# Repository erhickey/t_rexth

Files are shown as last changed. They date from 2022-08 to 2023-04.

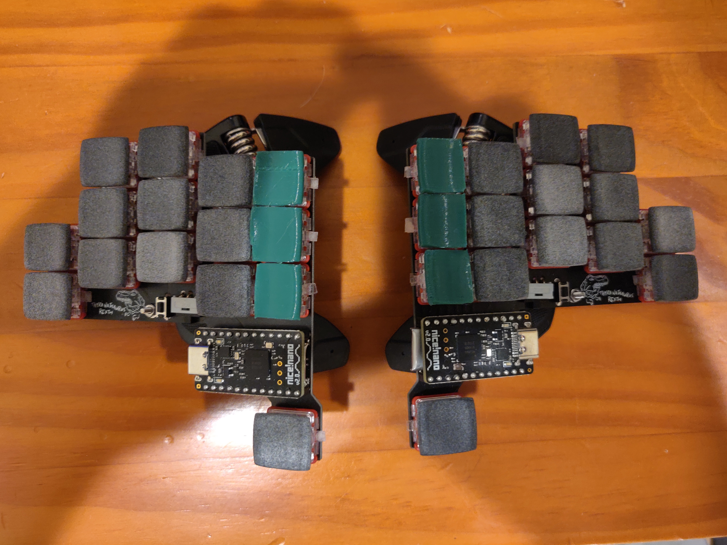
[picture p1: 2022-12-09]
pics/choc30_double.jpg

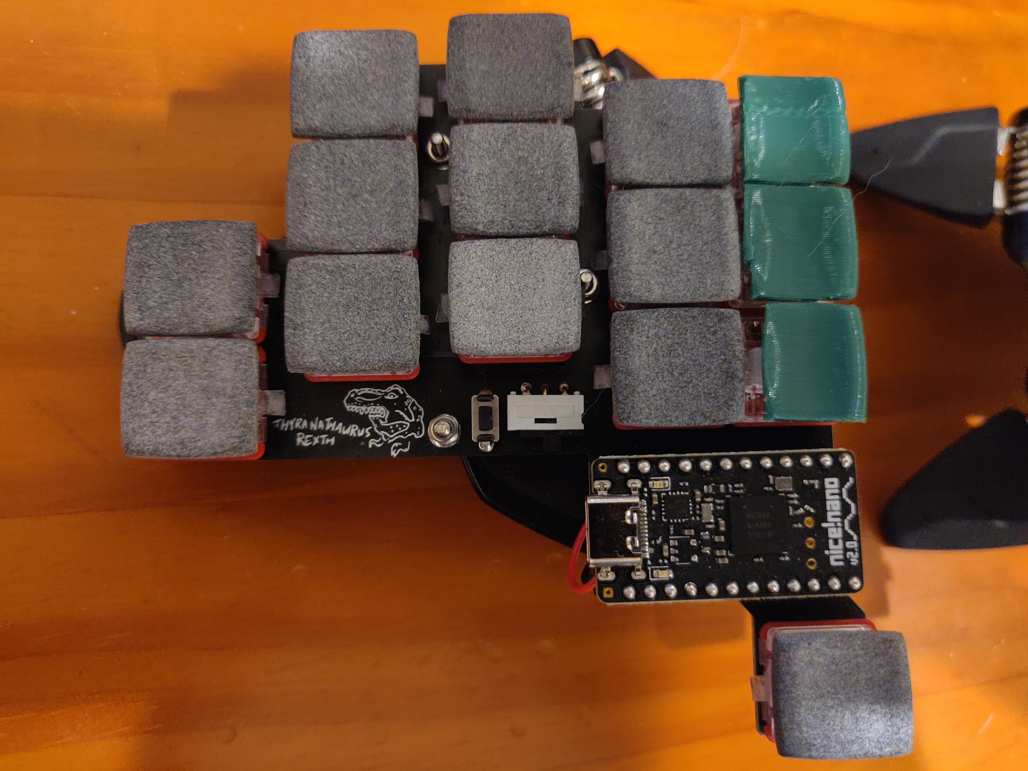
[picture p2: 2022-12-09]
pics/choc30_single.jpg

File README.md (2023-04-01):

# Thyranathaurus Rexth

t-rexth

## About

- Split Keyboard
- Wireless
- Ortholinear
- 36 keys
- MX switch compatible
- Hot swap sockets
- Tenting puck compatible

### Notes

PCB track width and spacing is 0.15mm. Make sure your manufacturer is capable of printing boards with those specs. I used [JLCPCB](https://jlcpcb.com/capabilities/pcb-capabilities).

## Credits/Thanks

- Motivated by [Ben Vallack's videos](https://www.youtube.com/channel/UC4NNPgQ9sOkBjw6GlkgCylg)
- Created with [Ergogen v3](https://github.com/ergogen/ergogen)
- Lots of help from members of [Ergogen Discord](https://discord.gg/nbKcAZB)
- Keycaps by [Pseudoku](https://github.com/pseudoku/PseudoMakeMeKeyCapProfiles)
- Artwork by [Perce](https://madebyperce.com)
- Tenting Puck by [lacohe](https://www.thingiverse.com/thing:5336898)

## Parts

| Type | Part | Manufacturer |
|---|---|---|
| Tactile Button | [C&K PTS636 SP43 LFS](https://www.mouser.com/ProductDetail/CK/PTS636-SP43-LFS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) | [C&K Switches](https://www.ckswitches.com/media/2779/pts636.pdf) |
| Slide Switch | [EAO 09.10290.01](https://www.mouser.com/ProductDetail/EAO/091029001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) | [EAO](https://eao.com) |
| Machine Pin Sockets | [Mill-Max 801 INTERCONNECT MACHINED PIN SOCKET](https://www.mouser.com/ProductDetail/Mill-Max/801-47-012-10-012000?qs=5aG0NVq1C4x40xNvDlnKzg%3D%3D) | [Mill-Max](https://www.mill-max.com/products/socket/801-xx-xxx-10-012000) |
| Socket Pins | [Mill-Max 3330 Straight Pin](https://www.mouser.com/ProductDetail/Mill-Max/3330-0-00-15-00-00-03-0?qs=s8Nb1z4Wn%2FSwJBcI97lmUw%3D%3D) | [Mill-Max](https://www.mill-max.com/products/pin/3330) |
| JST PH 2.0 Connector | [TE 1775469-2](https://www.mouser.com/ProductDetail/TE-Connectivity/1775469-2?qs=fvVej%2FMj3jdYOde%252BssG5lg%3D%3D) | [TE Connectivity](https://www.te.com/usa-en/product-1775469-2.html) |

## Choc 30

The [choc30](./choc30) folder contains the first design of this keyboard. It has 30 keys, requires choc compatible switches, and has minimal y spacing. I abandoned that version for a couple reasons. I found the keycaps and spacing too small, and I could not find an enjoyable 30 key layout.

If you are interested in that version beware of a couple issues:

- Attempting to solder battery wires onto the PCB without shorting your battery can be tricky.
- The spacing between the innermost columns is not wide enough, thus the philadelphia minimalist keycaps [do not fit both columns](./pics/choc30_single.jpg).

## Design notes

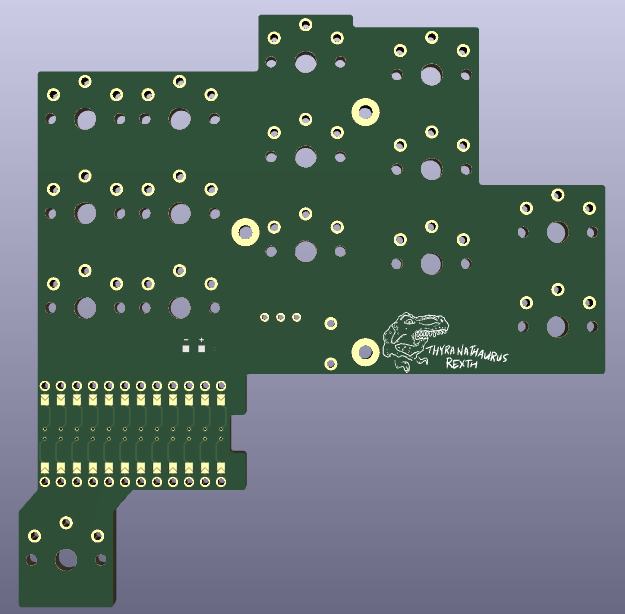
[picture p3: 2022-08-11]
pics/choc30_pcb_3d.png

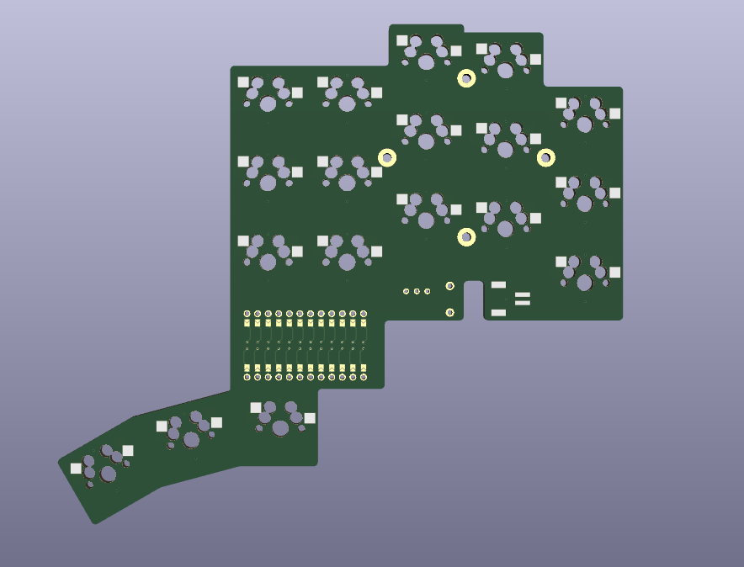
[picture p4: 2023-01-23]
pics/pcb_3d.png

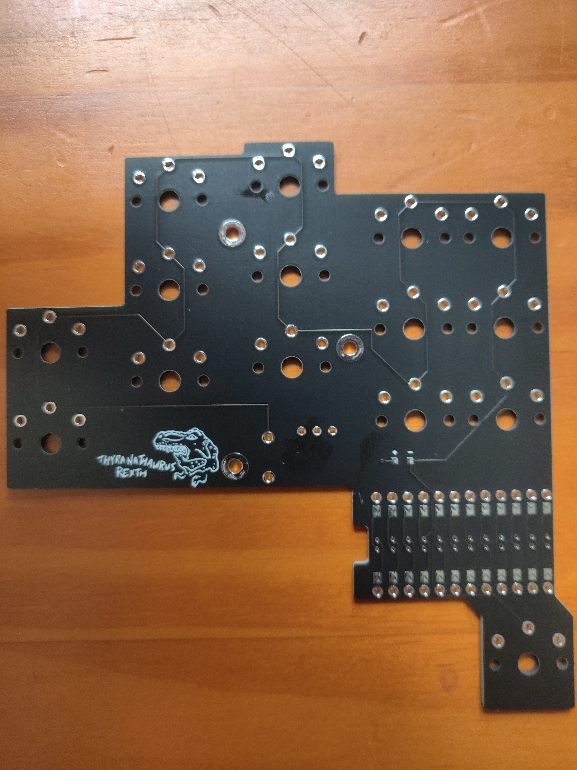
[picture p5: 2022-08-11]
pics/choc30_pcb_back.jpg

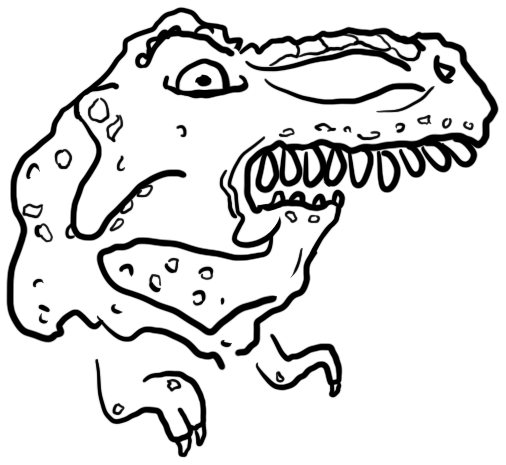
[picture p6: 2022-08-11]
artwork/drawing_cropped.png

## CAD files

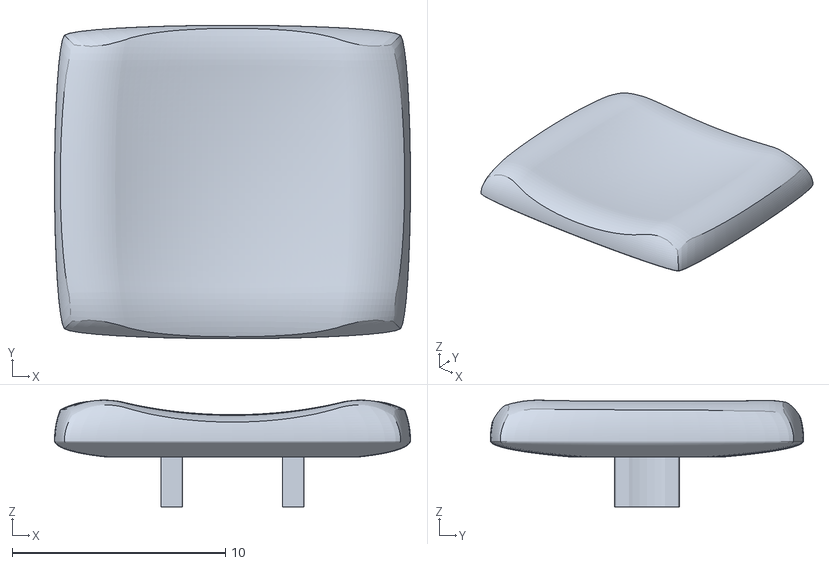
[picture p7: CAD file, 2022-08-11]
keycaps/PM_full_choc_x_min_choc_y.stl
16.7 x 14.7 x 5.01

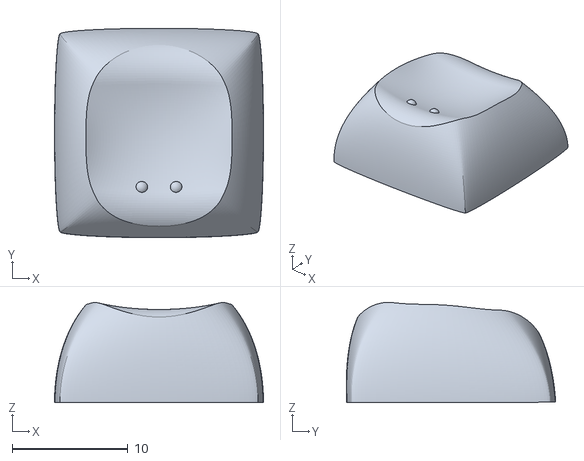
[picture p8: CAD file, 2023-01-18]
keycaps/DES_1u_alphas/R3H.stl
18.1 x 18.1 x 8.66

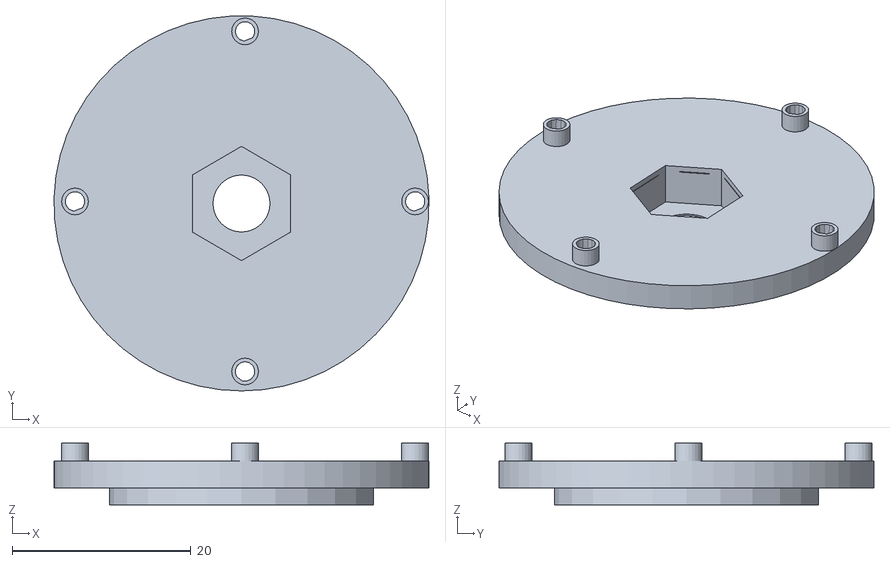
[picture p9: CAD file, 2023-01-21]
puck/puckv2.stl
42.0 x 42.0 x 6.90

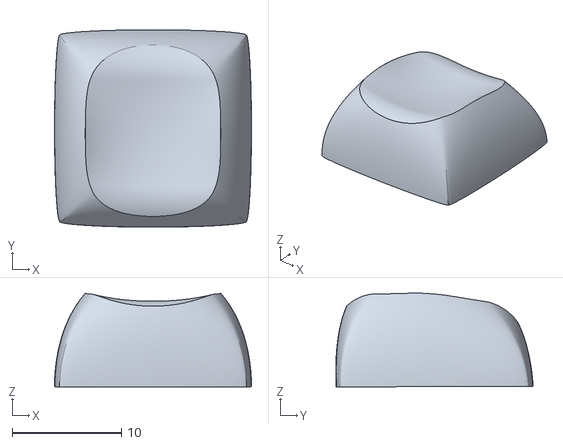
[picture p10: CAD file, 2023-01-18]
keycaps/DES_1u_alphas/R3.stl
18.1 x 18.1 x 8.60

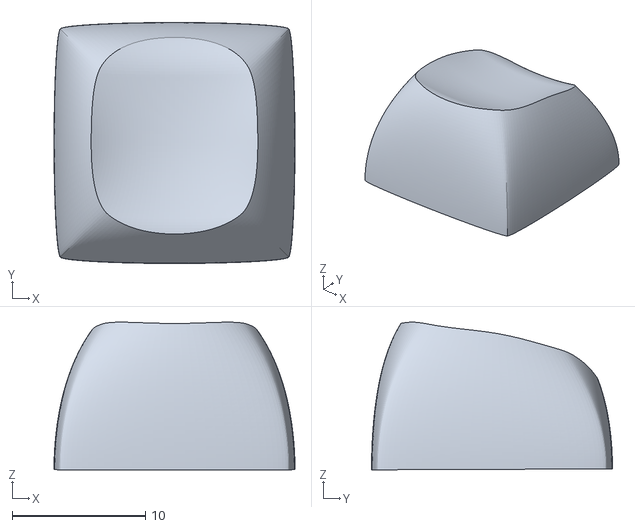
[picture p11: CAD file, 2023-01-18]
keycaps/DES_1u_alphas/R4.stl
18.1 x 18.1 x 11.1

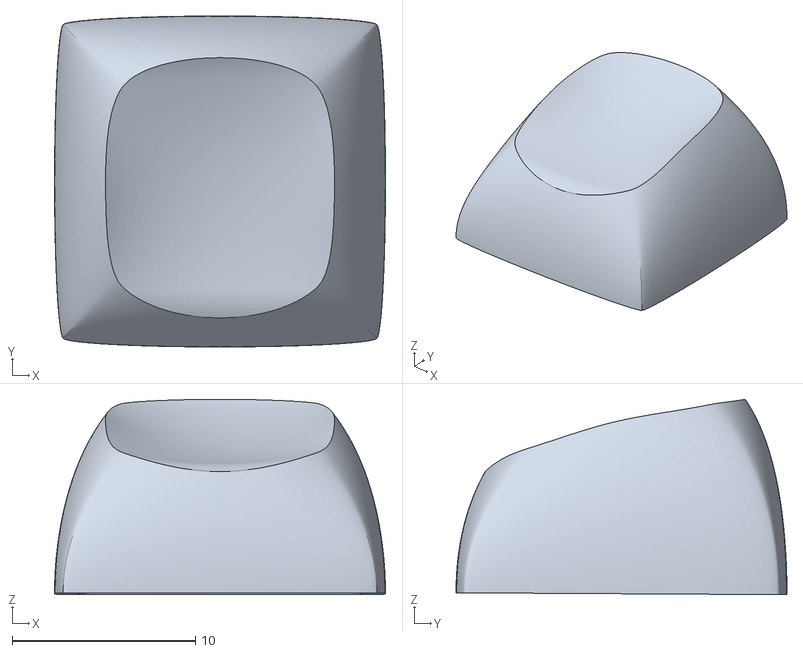
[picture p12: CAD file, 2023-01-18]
keycaps/DES_1u_alphas/R2.stl
18.1 x 18.1 x 10.7

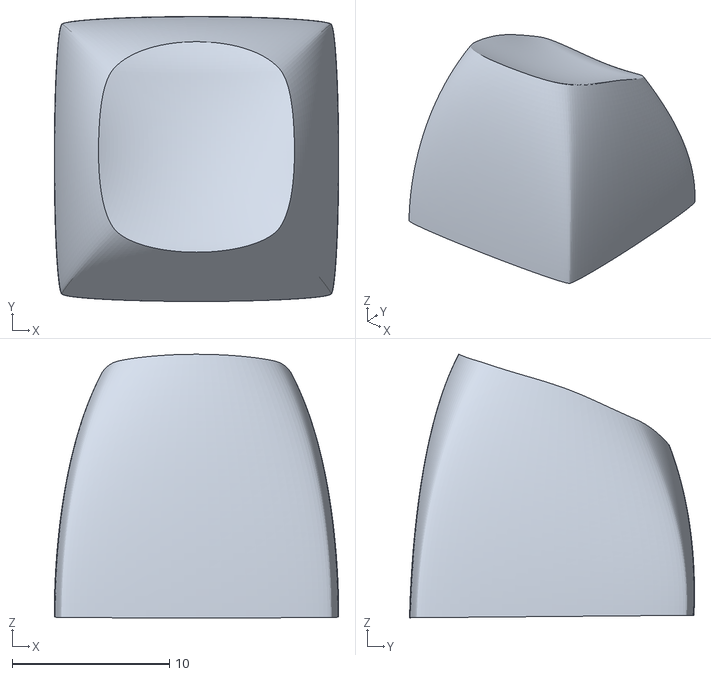
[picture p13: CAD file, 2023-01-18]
keycaps/DES_1u_alphas/R1.stl
18.1 x 18.1 x 16.7

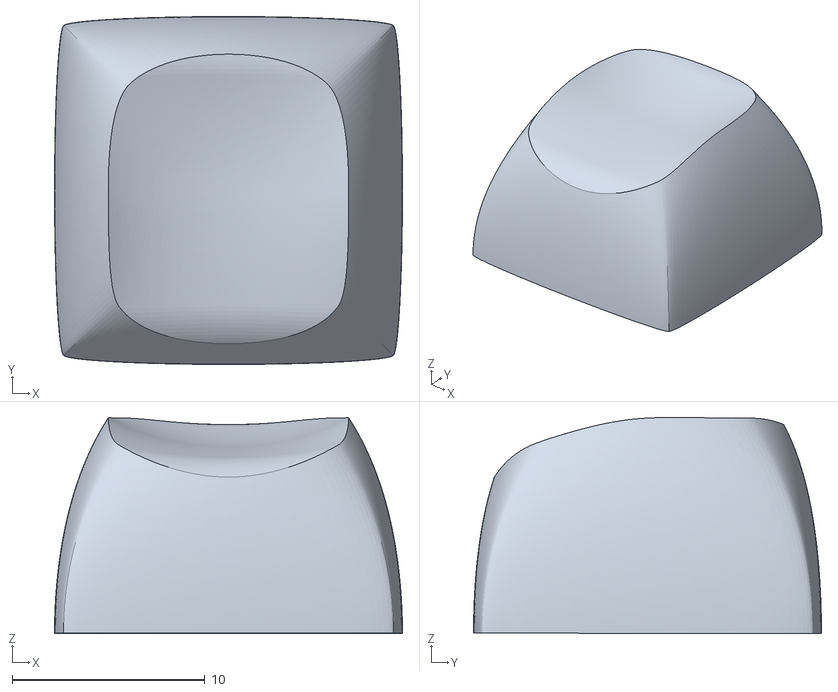
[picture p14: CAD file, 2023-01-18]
keycaps/DES_1u_alphas/R5.stl
18.1 x 18.1 x 11.2

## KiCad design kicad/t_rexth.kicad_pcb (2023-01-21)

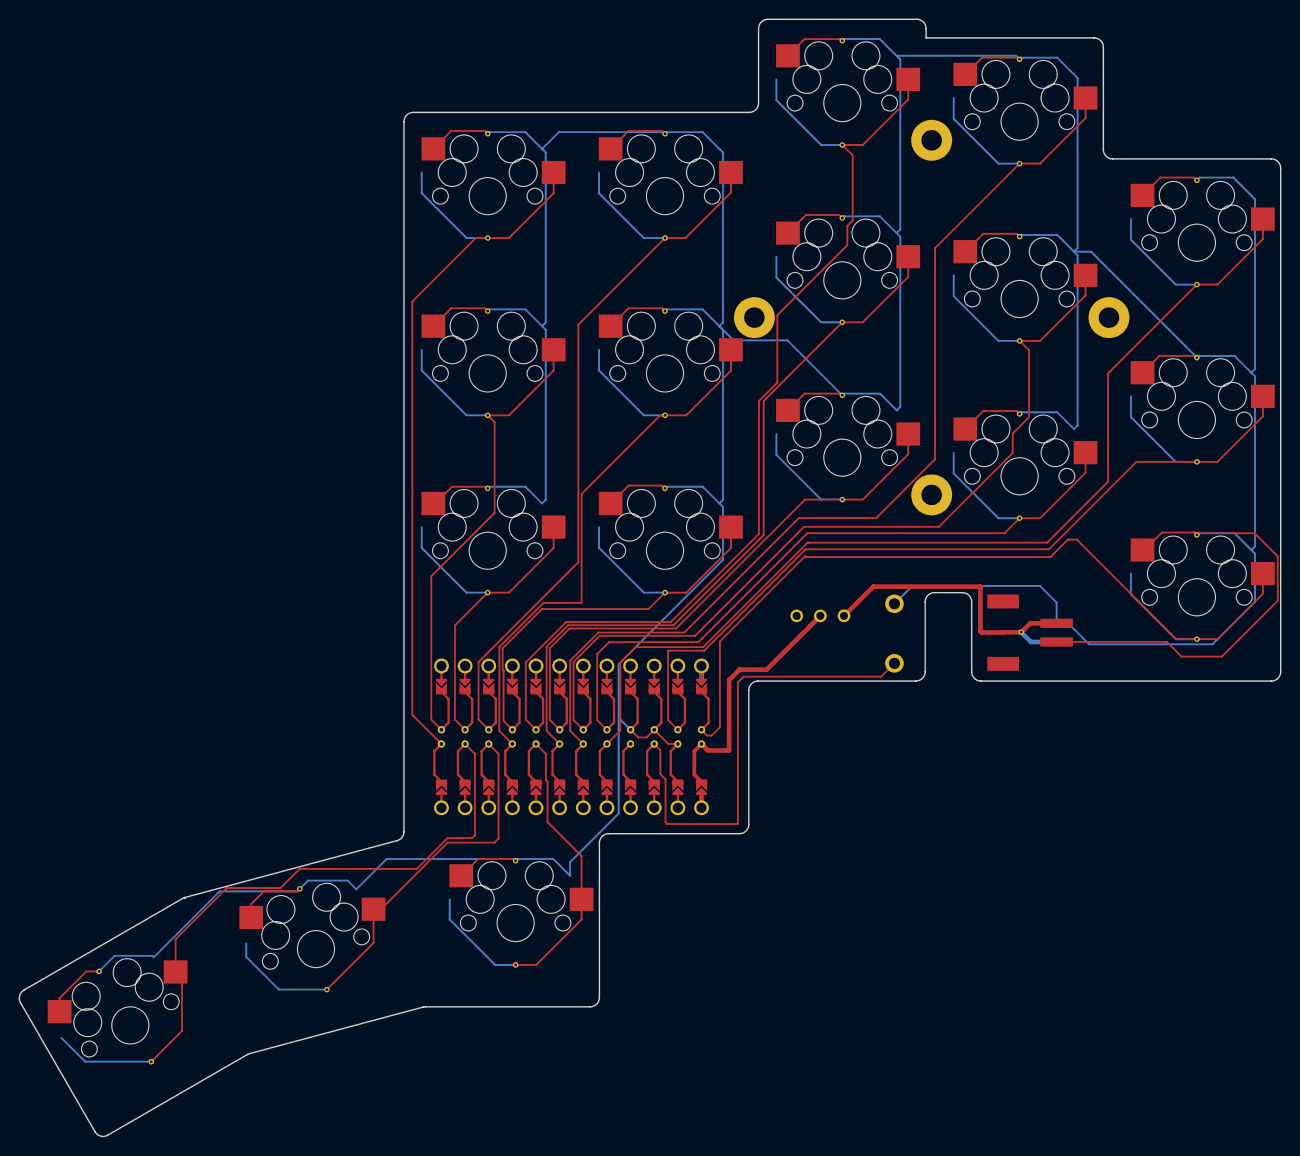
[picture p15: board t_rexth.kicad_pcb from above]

Board: 2 copper layers, 135.5 x 120.0 mm, 23 parts (0 on the bottom side), 22 nets.

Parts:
B1: RST; PTS636
JST_PH_SMD1: 17754692
MCU1: ProMicro
S1, S2, S3, S4, S5, S6, S7, S8, S9, S10, S11, S12, S13, S14, S15, S16, S17, S18: MX
T1: SWITCH_09-10290_EOZ
_2: Tenting Puck

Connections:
BATT: JST_PH_SMD1.1, JST_PH_SMD1.2, T1.2
GND: B1.1, JST_PH_SMD1.1, JST_PH_SMD1.2, MCU1.2, MCU1.21, MCU1.22, S1.1, S1.2, S2.1, S2.2, S3.1, S3.2, S4.1, S4.2, S5.1, S5.2, S6.1, S6.2, S7.1, S7.2, S8.1, S8.2, S9.1, S9.2, S10.1, S10.2, S11.1, S11.2, S12.1, S12.2, S13.1, S13.2, S14.1, S14.2, S15.1, S15.2, S16.1, S16.2, S17.1, S17.2, S18.1, S18.2
P0: MCU1.23, S14.1
P1: MCU1.24, S13.1
P2: MCU1.20, S10.1
P3: MCU1.19, S11.1
P4: MCU1.18, S7.1
P5: MCU1.17, S9.1
P6: MCU1.16, S4.1
P7: MCU1.15, S6.1
P8: MCU1.14, S1.1
P9: MCU1.13, S2.1
P10: MCU1.12, S3.1
P14: MCU1.10, S17.1
P15: MCU1.9, S5.1
P16: MCU1.11, S18.1
P18: MCU1.8, S16.1
P19: MCU1.7, S8.1
P20: MCU1.6, S12.1
P21: MCU1.5, S15.1
RAW: MCU1.1, T1.1
RST: B1.2, MCU1.3

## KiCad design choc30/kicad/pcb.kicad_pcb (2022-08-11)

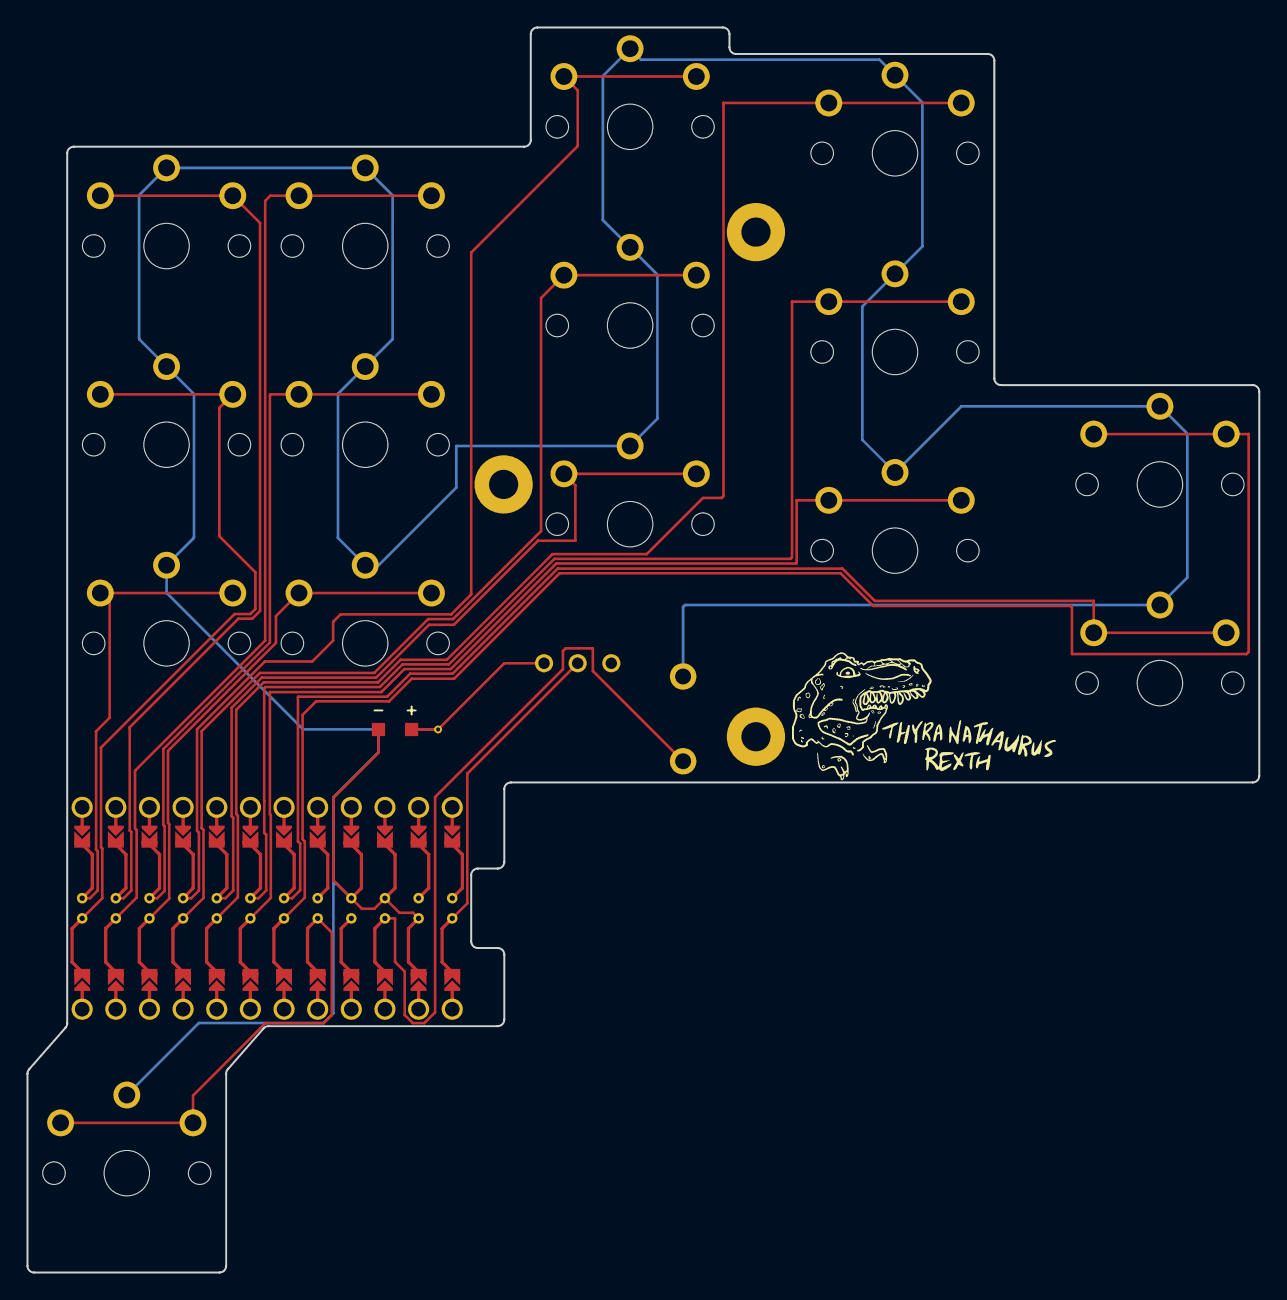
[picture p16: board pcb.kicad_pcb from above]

Board: 2 copper layers, 93.0 x 94.0 mm, 21 parts (0 on the bottom side), 19 nets.

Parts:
B1: RST; PTS636
MCU1: ProMicro
PAD1, PAD2: SMDPad
S1, S2, S3, S4, S5, S6, S7, S8, S9, S10, S11, S12, S13, S14, S15: PG1350
T1: SWITCH_09-10290_EOZ
_2: Tenting Puck

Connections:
BATT: PAD1.1, T1.3
GND: B1.1, MCU1.2, MCU1.21, MCU1.22, PAD2.1, S1.2, S2.2, S3.2, S4.2, S5.2, S6.2, S7.2, S8.2, S9.2, S10.2, S11.2, S12.2, S13.2, S14.2, S15.2
P3: MCU1.19, S13.1
P4: MCU1.18, S11.1
P5: MCU1.17, S7.1
P6: MCU1.16, S9.1
P7: MCU1.15, S5.1
P8: MCU1.14, S3.1
P9: MCU1.13, S1.1
P10: MCU1.12, S2.1
P14: MCU1.10, S4.1
P15: MCU1.9, S8.1
P16: MCU1.11, S6.1
P18: MCU1.8, S12.1
P19: MCU1.7, S10.1
P20: MCU1.6, S14.1
P21: MCU1.5, S15.1
RAW: MCU1.1, T1.1
RST: B1.2, MCU1.3

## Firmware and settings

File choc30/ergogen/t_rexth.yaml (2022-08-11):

units:
  u: 15
  cap_size: 15
  finger_spread: 20
  column_gap: finger_spread - cap_size
  edge_padding: 0
  middle_stagger: 9
  ring_stagger: -2
  pinky_stagger: -10
  thumb_offset_x: -3
  thumb_offset_y: -25 - cap_size
  pinky_to_bottom: edge_padding
  ring_to_bottom: -1 pinky_stagger + pinky_to_bottom
  middle_to_bottom: -1 ring_stagger + ring_to_bottom
  thumb_gap: (-1 thumb_offset_y) - cap_size
  index_to_bottom: thumb_gap - 3.6

points:
  key:
    padding: cap_size

    footprints:
      choc:
        type: choc
        nets:
          from: =net_from
          to: GND
        params:
          reverse: true
          hotswap: false
          keycaps: false

  zones:
    fingers:
      anchor: # move schematic inside outline in kicad
        shift: [140, -160]

      columns:

        inner:
          rows:
            bottom:
              net_from: P9
              # top, right, bottom, left
              bind: [0, 0, index_to_bottom, edge_padding]
            home:
              net_from: P10
              bind: [0, 0, 0, edge_padding]
            top:
              net_from: P8
              bind: [edge_padding, 0, 0, edge_padding]

        index:
          spread: cap_size
          rows:
            bottom:
              net_from: P14
              bind: [0, column_gap - 2, index_to_bottom, 0]
            home:
              net_from: P7
              bind: [0, column_gap, 0, 0]
            top:
              net_from: P16
              bind: [edge_padding, column_gap, 0, 0]

        middle:
          spread: finger_spread
          stagger: middle_stagger
          rows:
            bottom:
              net_from: P5
              bind: [0, edge_padding, middle_to_bottom, column_gap]
            home:
              net_from: P15
              bind: [0, edge_padding, 0, edge_padding]
            top:
              net_from: P6
              bind: [edge_padding, edge_padding, 0, edge_padding]

        ring:
          spread: finger_spread
          stagger: ring_stagger
          rows:
            bottom:
              net_from: P19
              bind: [0, edge_padding, ring_to_bottom, column_gap]
            home:
              net_from: P4
              bind: [0, edge_padding, 0, column_gap]
            top:
              net_from: P18
              bind: [edge_padding, edge_padding, 0, column_gap]

        pinky:
          spread: finger_spread
          stagger: pinky_stagger
          rows:
            bottom:
              net_from: P3
              bind: [0, edge_padding, pinky_to_bottom, column_gap]
            home:
              net_from: P20
              bind: [edge_padding, edge_padding, 0, column_gap]

    thumbs:
      anchor:
        ref: fingers_inner_bottom
        shift: [thumb_offset_x, thumb_offset_y]

      columns:
        thumb:
          rows:
            home:
              net_from: P21
              bind: [0, 0, 0, 0]

outlines:
  exports:
    raw:
      - type: keys
        side: left
        size: [cap_size, cap_size]
      - type: polygon
        points:
          - ref: thumbs_thumb_home
            shift: [-4, 11.7]
          - shift: [-3.5, -4]
          - shift: [0, -15.2]
          - shift: [15, 0]
          - shift: [0, 15.2]
          - shift: [3.5, 4]
      - operation: subtract
        type: rectangle
        anchor:
          ref: fingers_index_bottom
          shift: [8, -23]
        size: [3, 6]

    edge:
      - type: outline
        name: raw
        fillet: 0.5
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

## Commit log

2022-08-11 bare pcb pics
2023-01-18 start mx version
    [R1.stl, R2.stl, R3.stl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]
2023-01-21 mx version progress
    [pcb.kicad_pcb, puckv2.stl, t_rexth.kicad_pcb]
2023-01-23 update pcb 3d pic
